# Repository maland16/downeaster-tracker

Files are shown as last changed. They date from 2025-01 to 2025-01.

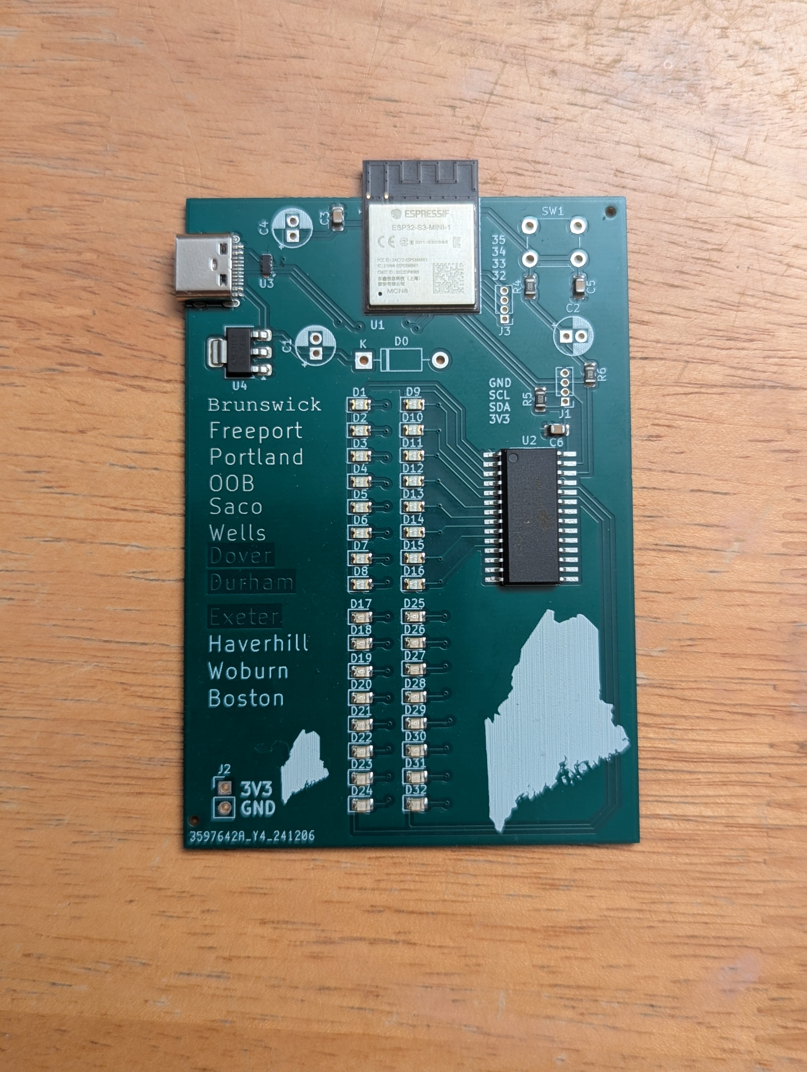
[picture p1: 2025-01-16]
PCB/Rev0 - Test Board/PXL_20250116_013609720.jpg

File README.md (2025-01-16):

# downeaster-tracker
A ESP-32 based train tracker for the Amtrak Downeaster
# Inspiration
This project was inspired by the [TrainTrackr line of PCB based LED live train maps](https://www.traintrackr.io/). The PCB design is a mishmash of [their open source board design](https://github.com/Traintrackr/board_files) as well as various [ESP-32 PCB design youtube videos](https://www.youtube.com/watch?v=jiJGbWOSdMo) and online resources. 

# A footnote on the HT16K33
I have a mixed review of this LED driver. On one hand, its age and extensive use in the DIY electronics space means it has pretty robust support. On the other hand, it's old. I wasn't able to source any from the usual suspects (digikey, mouser, etc.) and resorted to picking some up on Ebay. The kicad footprint and symbol are in /PCB. Also, despite the datasheet saying otherwise, it seems as though it can run just fine at 3.3V, and is used extensively in production designs at that voltage.

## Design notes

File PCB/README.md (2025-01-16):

## Issues with Rev0
- Boot pin isn't connected to anything :(
-

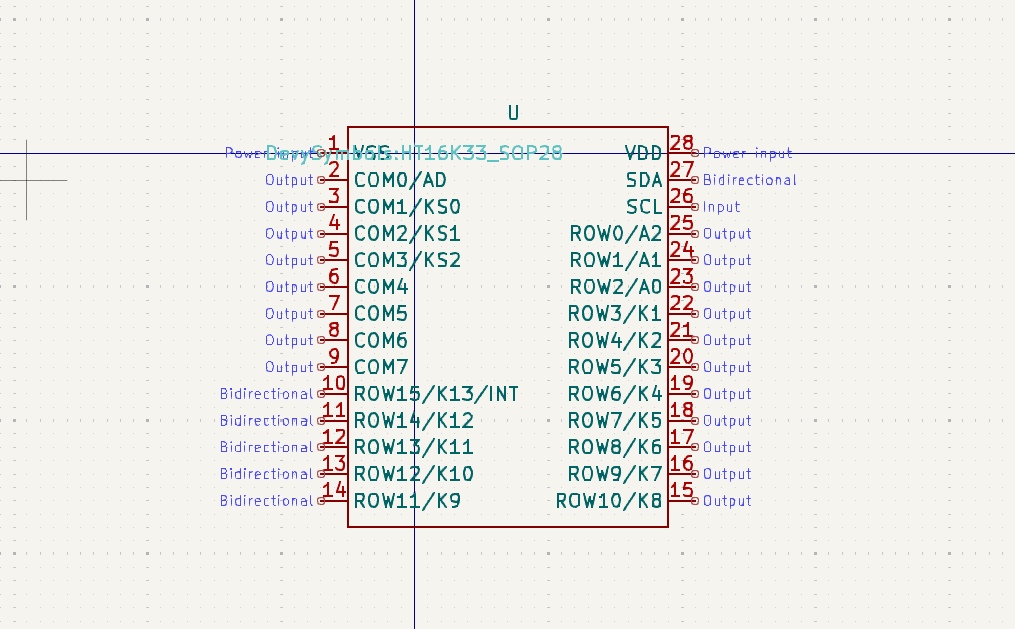
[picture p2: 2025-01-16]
PCB/HT16K33_SOP28/HT16K33_LEDDRIVER.png

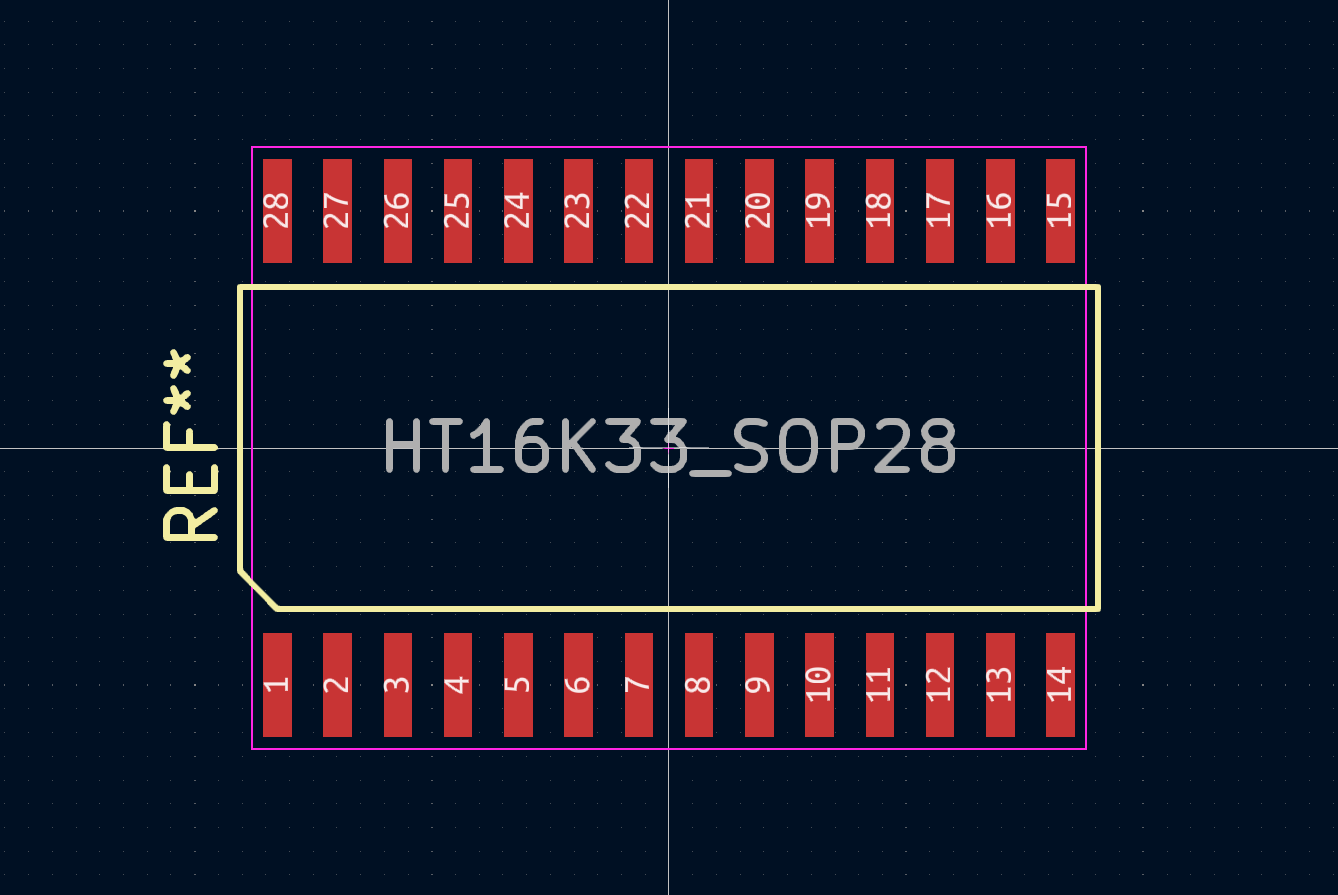
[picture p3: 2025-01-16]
PCB/HT16K33_SOP28/HT16K33_SOP28.png

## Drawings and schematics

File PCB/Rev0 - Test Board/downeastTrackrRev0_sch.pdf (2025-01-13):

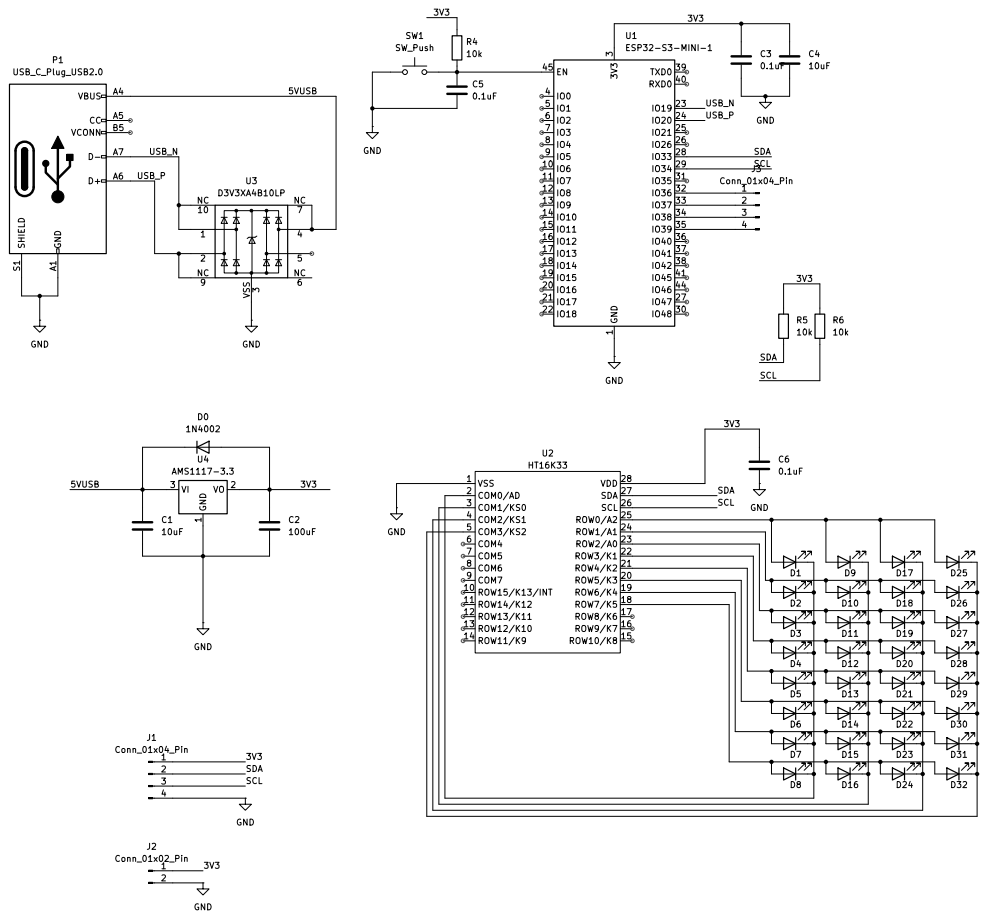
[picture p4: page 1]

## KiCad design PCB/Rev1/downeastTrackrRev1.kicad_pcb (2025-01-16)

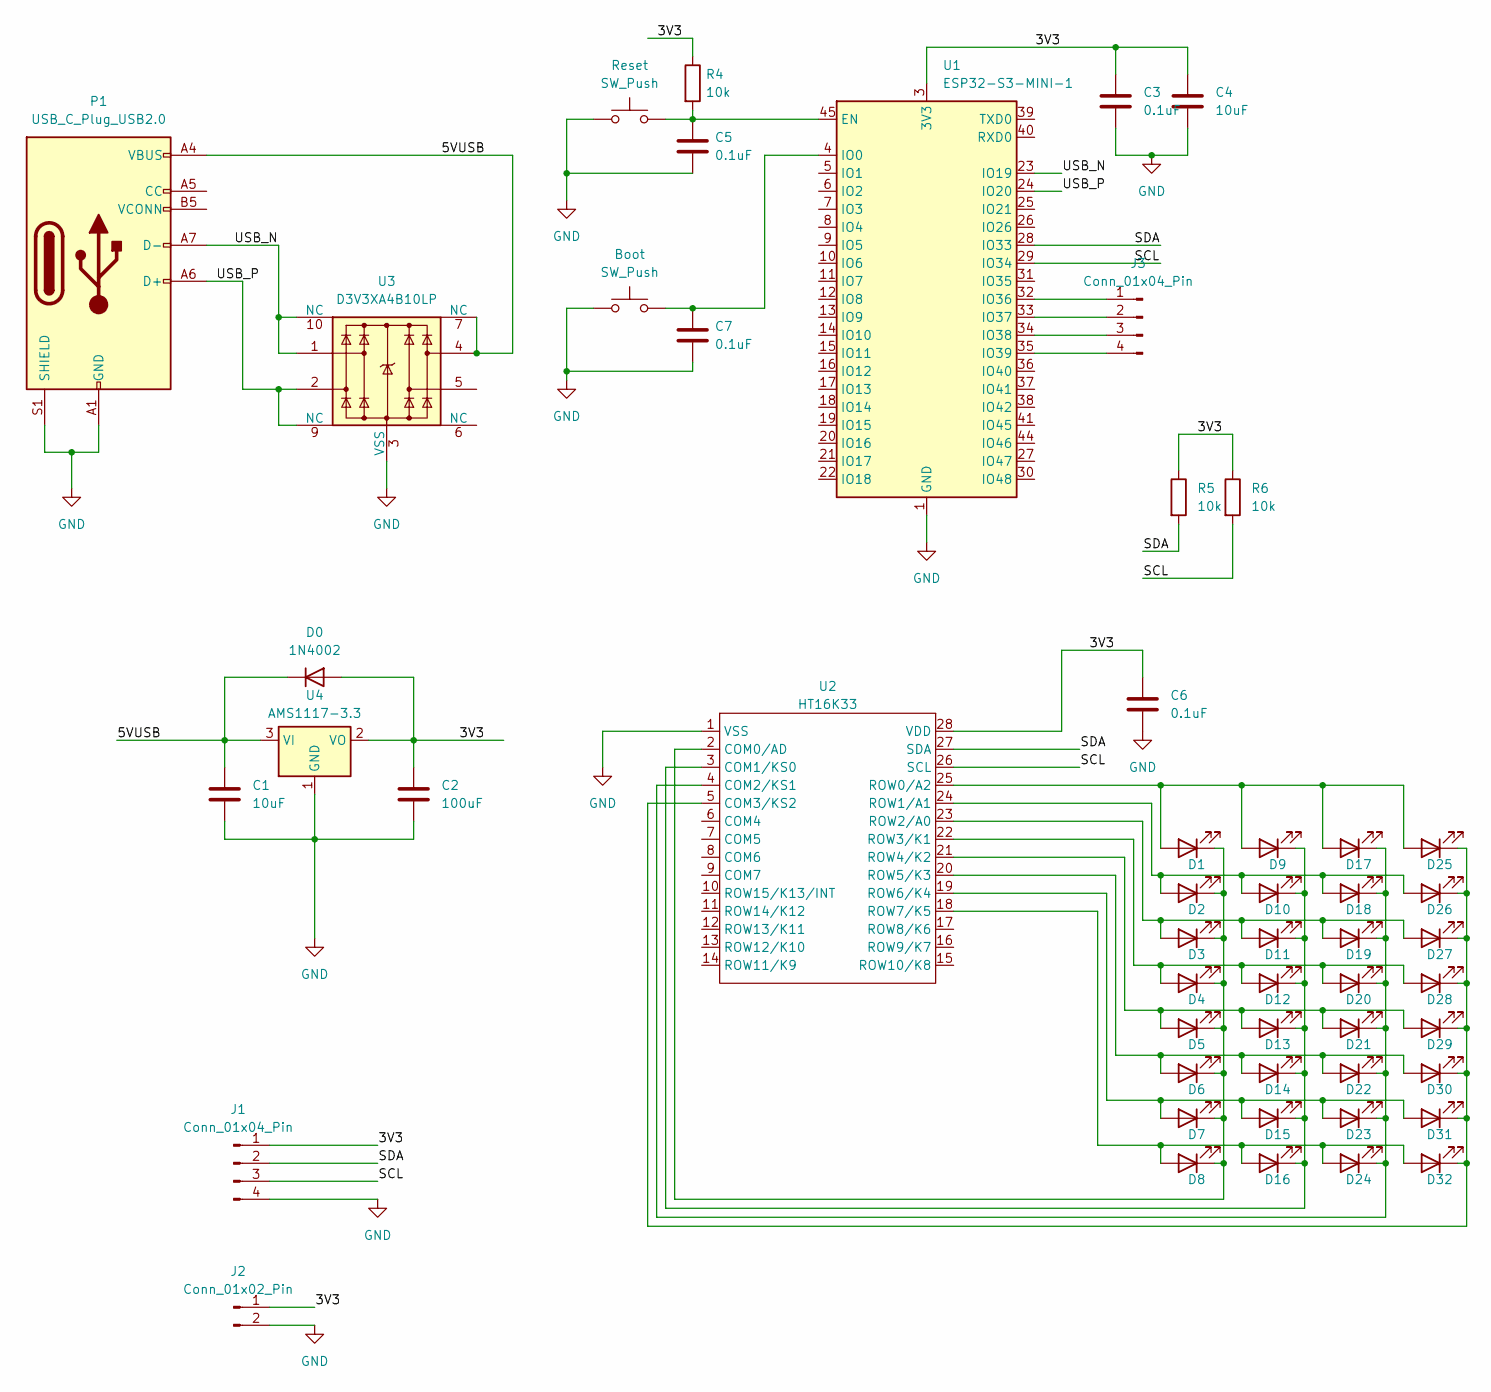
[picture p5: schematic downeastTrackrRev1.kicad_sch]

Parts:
Boot: SW_Push; SW_PUSH_6mm
C1, C4: 10uF; CP_Radial_D5.0mm_P2.00mm
C2: 100uF; CP_Radial_D5.0mm_P2.00mm
C3, C5, C6, C7: 0.1uF; C_0805_2012Metric_Pad1.18x1.45mm_HandSolder; LCSC C28233
D0: 1N4002; D_DO-41_SOD81_P10.16mm_Horizontal
D1, D2, D3, D4, D5, D6, D7, D8, D9, D10, D11, D12, D13, D14, D15, D16: LED; LED_0805_2012Metric; LCSC C84259
D17, D18, D19, D20, D21, D22, D23, D24, D25, D26, D27, D28, D29, D30, D31, D32: LED; LED_0805_2012Metric; LCSC C84260
J1, J3: Conn_01x04_Pin; PinHeader_1x04_P1.27mm_Vertical
J2: Conn_01x02_Pin; PinHeader_1x02_P2.54mm_Vertical
P1: USB_C_Plug_USB2.0; USB_C_Receptacle_HRO_TYPE-C-31-M-12; LCSC C165948
R4, R5, R6: 10k; R_0805_2012Metric_Pad1.20x1.40mm_HandSolder; LCSC C17414
Reset: SW_Push; SW_PUSH_6mm
U1: ESP32-S3-MINI-1; ESP32-S2-MINI-1; LCSC C2913206
U2: HT16K33; HT16K33_SOP28
U3: D3V3XA4B10LP; Diodes_UDFN-10_1.0x2.5mm_P0.5mm; LCSC C1980462
U4: AMS1117-3.3; SOT-223-3_TabPin2; LCSC C6186

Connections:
/3V3: C2.1, C3.1, C4.1, C6.1, D0.2 (A), J1.1, J2.1, R4.1, R5.1, R6.1, U1.3 (3V3), U2.28 (VDD), U4.2 (VO)
/5VUSB: C1.1, D0.1 (K), P1.A4 (VBUS), P1.A9 (VBUS), P1.B4 (VBUS), P1.B9 (VBUS), U3.4, U3.7 (NC), U4.3 (VI)
/SCL: J1.3, R6.2, U1.29 (IO34), U2.26 (SCL)
/SDA: J1.2, R5.2, U1.28 (IO33), U2.27 (SDA)
/USB_N: P1.A7 (D-), U1.23 (IO19), U3.1, U3.10 (NC)
/USB_P: P1.A6 (D+), U1.24 (IO20), U3.2, U3.9 (NC)
GND: Boot.1, C1.2, C2.2, C3.2, C4.2, C5.2, C6.2, C7.2, J1.4, J2.2, P1.A1 (GND), P1.A12 (GND), P1.B1 (GND), P1.B12 (GND), P1.S1 (SHIELD), Reset.1, U1.1 (GND), U1.2 (GND), U1.42 (GND), U1.43 (GND), U1.46 (GND), U1.47 (GND), U1.48 (GND), U1.49 (GND), U1.50 (GND), U1.51 (GND), U1.52 (GND), U1.53 (GND), U1.54 (GND), U1.55 (GND), U1.56 (GND), U1.57 (GND), U1.58 (GND), U1.59 (GND), U1.60 (GND), U1.61 (GND), U1.62 (GND), U1.63 (GND), U1.64 (GND), U1.65 (GND), U2.1 (VSS), U3.3 (VSS), U3.8 (VSS), U4.1 (GND); also elsewhere on the board
unnamed: Boot.2, C7.1, U1.4 (IO0)
unnamed: D1.2 (A), D9.2 (A), D17.2 (A), D25.2 (A), U2.25 (ROW0/A2)
unnamed: D1.1 (K), D2.1 (K), D3.1 (K), D4.1 (K), D5.1 (K), D6.1 (K), D7.1 (K), D8.1 (K), U2.2 (COM0/AD)
unnamed: D2.2 (A), D10.2 (A), D18.2 (A), D26.2 (A), U2.24 (ROW1/A1)
unnamed: D9.1 (K), D10.1 (K), D11.1 (K), D12.1 (K), D13.1 (K), D14.1 (K), D15.1 (K), D16.1 (K), U2.3 (COM1/KS0)
unnamed: D3.2 (A), D11.2 (A), D19.2 (A), D27.2 (A), U2.23 (ROW2/A0)
unnamed: D4.2 (A), D12.2 (A), D20.2 (A), D28.2 (A), U2.22 (ROW3/K1)
unnamed: D5.2 (A), D13.2 (A), D21.2 (A), D29.2 (A), U2.21 (ROW4/K2)
unnamed: D6.2 (A), D14.2 (A), D22.2 (A), D30.2 (A), U2.20 (ROW5/K3)
unnamed: D7.2 (A), D15.2 (A), D23.2 (A), D31.2 (A), U2.19 (ROW6/K4)
unnamed: D8.2 (A), D16.2 (A), D24.2 (A), D32.2 (A), U2.18 (ROW7/K5)
unnamed: D17.1 (K), D18.1 (K), D19.1 (K), D20.1 (K), D21.1 (K), D22.1 (K), D23.1 (K), D24.1 (K), U2.4 (COM2/KS1)
unnamed: D25.1 (K), D26.1 (K), D27.1 (K), D28.1 (K), D29.1 (K), D30.1 (K), D31.1 (K), D32.1 (K), U2.5 (COM3/KS2)
unnamed: J3.1, U1.32 (IO36)
unnamed: J3.2, U1.33 (IO37)
unnamed: J3.3, U1.34 (IO38)
unnamed: J3.4, U1.35 (IO39)
unnamed 24: C5.1, R4.2, Reset.2, U1.45 (EN); also elsewhere on the board

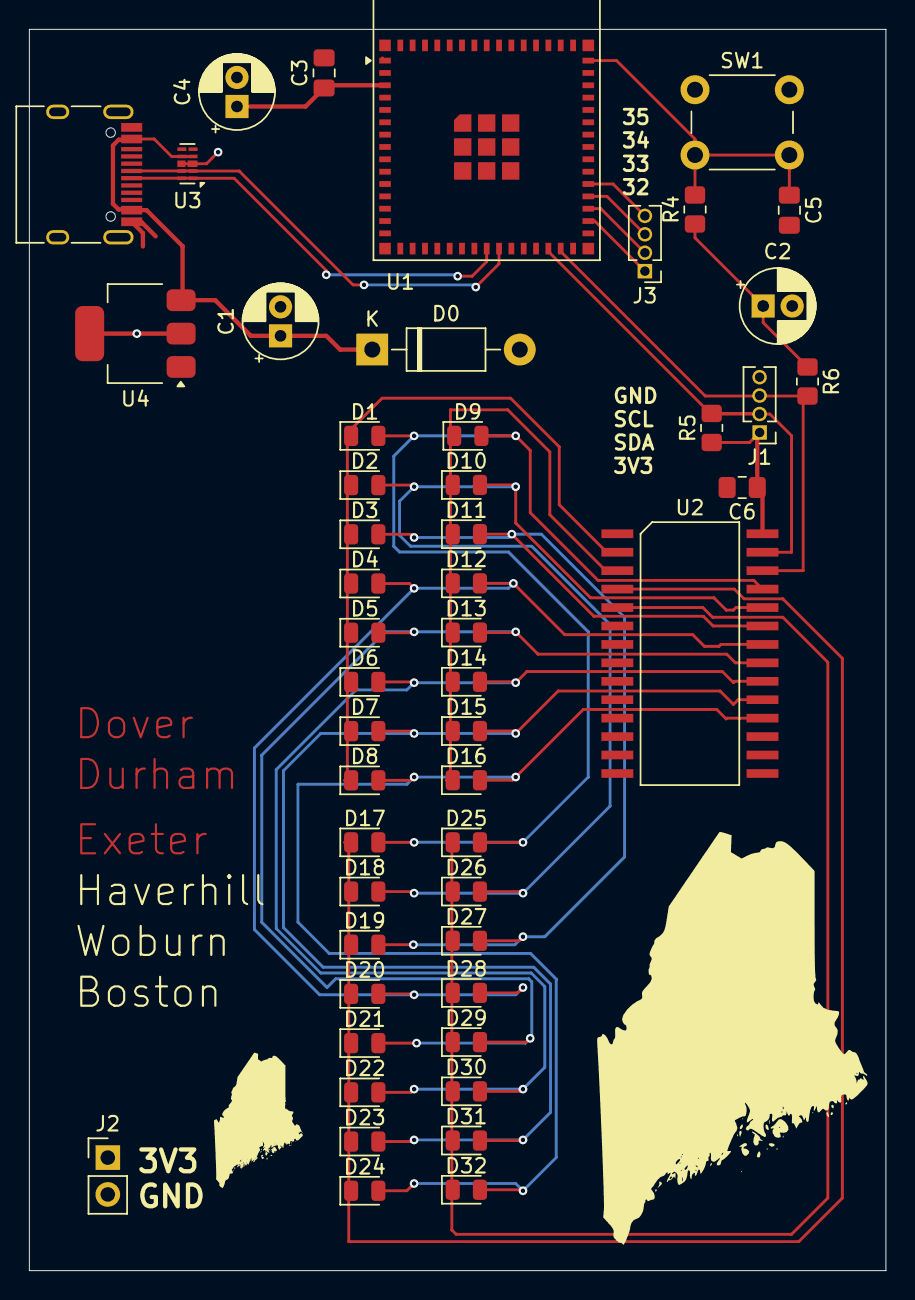
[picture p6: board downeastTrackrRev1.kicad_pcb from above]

Board: 4 copper layers, 59.0 x 85.5 mm, 51 parts (0 on the bottom side), 24 nets.

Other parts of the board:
SW1: SW_Push; SW_PUSH_6mm

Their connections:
GND: SW1.1; also elsewhere on the board
unnamed 24: SW1.2; also elsewhere on the board

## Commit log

2025-01-13 test script & rev0 PCB
    [downeastTrackrRev0.kicad_pcb, downeastTrackrRev0.kicad_sch]
2025-01-16 PythonParsingTest: Polished up & added station coords
    [downeasterStopCordinates.csv]
2025-01-16 Rev1: Started work on rev1
    [downeastTrackrRev1.kicad_pcb, downeastTrackrRev1.kicad_sch]
2025-01-16 PCB: Added HT16K33 driver resources
